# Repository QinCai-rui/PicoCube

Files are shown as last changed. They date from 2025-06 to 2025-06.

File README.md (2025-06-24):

# RasPiCube

## A Raspberry Pi-powered Rubik's Cube Timer

Rubik's Cube Timer

_NOTE: The image shows (simulated on Wokwi) demo powered by a Raspberry Pi Pico_

## Why I Made This Project

Honestly, I just wanted a cool timer for solving Rubik’s Cubes—something I could build myself, mess with, and show off to friends at school. The ones you can buy are fine, but making my own with a Raspberry Pi felt way more fun (and gave me an excuse to tinker with hardware and code). Now I’ve got a timer that does exactly what I want (although there are a few bugs to fix, and some features yet-to-be-implemented), and I learned a ton making it!! And it's portable, too! :)

## Overview

RasPiCube is a portable, Raspberry Pi Zero 2 W(H)-powered Rubik's Cube timer and scramble generator. This DIY project combines a high-resolution (320x240, pretty high) display, 7-segment timer, touch sensor input, and RGB status indicators to create a timing solution for cubers like myself.

### Features

- **Scramble Generation**: Automatically generates random, valid 3x3 Rubik's Cube scrambles
- **Dual Display System**: 
  - 2-inch IPS LCD Display (240×320) for scramble and statistics
  - 6-digit 7-segment display for precise timing readout (3d.p.)
- **Touch Sensor Input**: Capacitive touch controls for a competition-like solving experience 
- **Visual Status Indicators**: RGB LED provides clear visual feedback of the project's status
- **Statistics**: Calculates and displays session averages (ao5, ao12)
- **Battery Powered**: Portable with a 18650 lithium-ion battery

### Case (just a box for now. will modify it after getting the parts and done some measurements)



### Circuit diagram (in ASCII; it's bad, I know)

I couldn't find footprints/symbols for most of the parts I am using. Sooo.
 [diagram here](https://github.com/QinCai-rui/RasPiCube/blob/main/DIAGRAM/diagram.txt)

### What it will end up looking like

Note: this is a picture taken in Wokwi simulator, with a very early version of this project that (barely) runs on the Raspberry Pi Pico. 
Rubik's Cube Timer

## Hardware Components

For a complete list of components and estimated prices, please see [BOM.md](https://github.com/QinCai-rui/RasPiCube/blob/main/BOM/BOM.md).

## What’s What (What Each File/Folder Is For)

- **.gitignore** — Tells git which files/folders to ignore (so junk/config and cache files don’t get tracked).
- **BOM/** — Bill of Materials! All the parts I need and some prices. See this for shopping. (required by Highway)
- **CAD/** — 3D model files for the timer’s case. Print or edit them if you want to make/modify the enclosure.
  - `RasPiCube_Case.step` — The actual 3D model of the case.
- **DIAGRAM/** — Circuit diagrams and wiring info.
  - `diagram.txt` — Text version of the wiring/circuit diagram. (bc I couldn't find footprints/symbols for most of the parts I am using)
- **JOURNAL.md** — My build log, notes, and what worked/didn’t along the way.
- **LICENSE** — Legal stuff (open source license details).
- **README.md** — You’re reading it rn! All the info about the project.
- **pi02w-rubiks.py** — The main code that runs the timer and scramble generator on the RPi Zero 2 W.
- **proofOfConcept/** — Early test code and experiments before the main build. These can run on any OS with Python 3 installed. No special hardware needed.
  - `basic_scramble_3x3.py` — Simple script to generate 3x3 scrambles (terminal version).
  - `rubiks_terminal.py` — Terminal-based prototype timer/scrambler.

## Circuit Diagram

See [diagram.txt](DIAGRAM/diagram.txt).

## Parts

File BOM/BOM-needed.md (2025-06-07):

# PiCubeZero - Bill of Materials (parts needed)

---

## Core Components

| Component | Description | Quantity | Link | Est. Price (inc. shipping) | Purpose |
|---|---|---|---|---|---|
| 802.11ax USB adapter | WiFi 6, mt7921au, dual-band | 1 | [AliExpress](https://www.aliexpress.com/item/1005005935638503.html) | $1.72 | 5GHz WiFi 6 networking; our home network does not have working 2.4GHz..... |
| 2-inch IPS LCD Display | 240x320 ST7789, Waveshare compatible | 1 | [Amazon](https://www.amazon.com/LCD-2inch-Module-Compatible-Display/dp/B0DRS9YQCK) | $14.40 | Scramble/time/statistics display |
| 6-Digit 7-Segment Display| TM1637-compatible LED display module | 1 | [AliExpress](https://www.aliexpress.com/item/1005001582129952.html) | $2.64 | Real-time/final time display |
| TTP223 Touch Sensor | Capacitive touch sensor | 2 | [AliExpress](https://www.aliexpress.com/item/1005006153014582.html) | $1.70 | Start/stop timer input |
| RGB LED (Common Cathode) | 5mm tri-color diffused | 1 | [AliExpress](https://www.aliexpress.com/item/1005004963591071.html) | $3.18 (100x)| Status indicator (colour coding) |

---

## Additional Components & Accessories

| Component | Description | Quantity | Link | Est. Price | Purpose |
|---|---|---|---|---|---|
| Resistors | 220Ω for RGB LED (x3) | 3 | [AliExpress](https://www.aliexpress.com/item/1005008494728485.html) | $5.58 (600x) | Current limiting for RGB LED |
| Wires | Solid core, white, 24AWG | 10 metres | [AliExpress](https://www.aliexpress.com/item/1005006106330815.html) | $2.10 | Connecting components |
| Large Breadboard | 630 holes | 1 | [AliExpress](https://www.aliexpress.com/item/1005007085965483.html) | $1.54 | Housing the electronics |
| Protoboard | 400 holes | 5 | [AliExpress](https://www.aliexpress.com/item/1005007204514719.html) | $9.31 | To solder the electronics on |
| USB Cable | Data, USB 2.0, 1m | 1 | [AliExpress](https://www.aliexpress.com/item/1005007504624576.html) | $0.99 | For data transfer and Pi first-boot configuration |
| Foam Tape | Double Sided Adhesive Foam Tape - 1.5cm, 5m | 1 | [AliExpress](https://www.aliexpress.com/item/1005006891100106.html?) | $0.99 | Temporary mounting and fixing electronics |
| Li-ion Battery | 18650 3.7V 3500mAh | 1 | [AliExpress](https://www.aliexpress.com/item/1005008078553867.html) | $4.98 | Powering the electronics |
| Battery Charger & Booster | Charging Circuit Board Step Up Boost Power Supply Module; 2xUSB-A output | 1 | [AliExpress](https://www.aliexpress.com/item/1005007457573822.html) | $0.59 | Charging and converting battery to 5V |
| 18650 Holder | Holder with cable | 1 | [AliExpress](https://www.aliexpress.com/item/1005006089547043.html) | $0.99 | Holder for 18650 battery
---

## Totals

### AliExpress



US$46.81

### Amazon


US$16.56

### Grant Total
US$63.37 GRAND TOTAL

---

## Notes

- Use only 1 RGB LED from the pack of 100.
- Use only 3 resistors from the pack of 600.
- The microSD card (64GB) is more than sufficient for OS and solve log storage.
- All links and prices were last verified as of 2025-06-02.

---

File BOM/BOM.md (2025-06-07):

# PiCubeZero - Bill of Materials

---

## Core Components

| Component | Description | Quantity | Link | Est. Price (inc. shipping) | Purpose |
|---|---|---|---|---|---|
| Raspberry Pi Zero 2 WH | 1GHz quad-core ARM CPU with WiFi, BT, and header pins| 1 | [AliExpress](https://www.aliexpress.com/item/1005007982832720.html) | $24.93 | Main controller/computer for the timer |
| 802.11ax USB adapter | WiFi 6, mt7921au, dual-band | 1 | [AliExpress](https://www.aliexpress.com/item/1005005935638503.html) | $1.72 | 5GHz WiFi 6 networking; our home network does not have working 2.4GHz..... |
| 2-inch IPS LCD Display | 240x320 ST7789, Waveshare compatible | 1 | [Amazon](https://www.amazon.com/LCD-2inch-Module-Compatible-Display/dp/B0DRS9YQCK) | $14.40 | Scramble/time/statistics display |
| 6-Digit 7-Segment Display| TM1637-compatible LED display module | 1 | [AliExpress](https://www.aliexpress.com/item/1005001582129952.html) | $2.64 | Real-time/final time display |
| TTP223 Touch Sensor | Capacitive touch sensor | 2 | [AliExpress](https://www.aliexpress.com/item/1005006153014582.html) | $1.70 | Start/stop timer input |
| SanDisk Extreme microSD | 64GB, Class A2, 190MB/s | 1 | [Amazon](https://www.amazon.com/SanDisk-Extreme-microSDXC-Memory-Adapter/dp/B09X7C7LL1) | $11.27 | OS and storage |
| RGB LED (Common Cathode) | 5mm tri-color diffused | 1 | [AliExpress](https://www.aliexpress.com/item/1005004963591071.html) | $3.18 (100x)| Status indicator (colour coding) |

---

## Additional Components & Accessories

| Component | Description | Quantity | Link | Est. Price | Purpose |
|---|---|---|---|---|---|
| Resistors | 220Ω for RGB LED (x3) | 3 | [AliExpress](https://www.aliexpress.com/item/1005008494728485.html) | $5.58 (600x) | Current limiting for RGB LED |
| Wires | Solid core, white, 24AWG | 10 metres | [AliExpress](https://www.aliexpress.com/item/1005006106330815.html) | $2.10 | Connecting components |
| Large Breadboard | 630 holes | 1 | [AliExpress](https://www.aliexpress.com/item/1005007085965483.html) | $1.54 | Housing the electronics |
| Protoboard | 400 holes | 5 | [AliExpress](https://www.aliexpress.com/item/1005007204514719.html) | $9.31 | To solder the electronics on |
| USB Cable | Data, USB 2.0, 1m | 1 | [AliExpress](https://www.aliexpress.com/item/1005007504624576.html) | $0.99 | For data transfer and Pi first-boot configuration |
| Foam Tape | Double Sided Adhesive Foam Tape - 1.5cm, 5m | 1 | [AliExpress](https://www.aliexpress.com/item/1005006891100106.html?) | $0.99 | Temporary mounting and fixing electronics |
| Li-ion Battery | 18650 3.7V 3500mAh | 1 | [AliExpress](https://www.aliexpress.com/item/1005008078553867.html) | $4.98 | Powering the electronics |
| Battery Charger & Booster | Charging Circuit Board Step Up Boost Power Supply Module; 2xUSB-A output | 1 | [AliExpress](https://www.aliexpress.com/item/1005007457573822.html) | $0.59 | Charging and converting battery to 5V |
| 18650 Holder | Holder with cable | 1 | [AliExpress](https://www.aliexpress.com/item/1005006089547043.html) | $0.99 | Holder for 18650 battery
---

## Wiring Reference

| Component | Raspberry Pi Zero 2 W Connection |
|---|---|
| 2-inch LCD Display | VCC→3.3V, GND→GND, DIN/MOSI→GPIO10, CLK→GPIO11, CS→GPIO8, DC→GPIO25, RST→GPIO27, BL→GPIO24 |
| 6-Digit 7-Segment | CLK→GPIO5, DIO→GPIO6, VCC→5V, GND→GND |
| RGB LED (Common Cathode) | Common→GND, R→220Ω→GPIO17, G→220Ω→GPIO22, B→220Ω→GPIO4 |
| TTP223 Touch Sensor | Signal→GPIO23, VCC→3.3V, GND→GND |

---

## Notes

- Use only 1 RGB LED from the pack of 100.
- Use only 3 resistors from the pack of 600.
- The microSD card (64GB) is more than sufficient for OS and solve log storage.
- All links and prices were last verified as of 2025-06-02.

---

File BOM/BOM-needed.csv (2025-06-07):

Component | Description | Quantity | Link | Est. Price | Purpose
802.11ax USB adapter | WiFi 6, mt7921au, dual-band | 1 | https://www.aliexpress.com/item/1005005935638503.html | $1.72 | 5GHz WiFi 6 networking
2-inch IPS LCD Display | 240x320 ST7789, Waveshare compatible | 1 | https://www.amazon.com/LCD-2inch-Module-Compatible-Display/dp/B0DRS9YQCK | $14.40 | Scramble/time/statistics display
6-Digit 7-Segment Display | TM1637-compatible LED display module | 1 | https://www.aliexpress.com/item/1005001582129952.html | $2.64 | Real-time/final time display
TTP223 Touch Sensor | Capacitive touch sensor | 2 | https://www.aliexpress.com/item/1005006153014582.html | $1.70 | Start/stop timer input
RGB LED (Common Cathode) | 5mm tri-color diffused | 1 | https://www.aliexpress.com/item/1005004963591071.html | $3.18 (100x) | Status indicator (colour coding)
Resistors | 220Ω for RGB LED (x3) | 3 | https://www.aliexpress.com/item/1005008494728485.html | $5.58 (600x) | Current limiting for RGB LED
Wires | Solid core, white, 24AWG | 10 metres | https://www.aliexpress.com/item/1005006106330815.html | $2.10 | Connecting components
Large Breadboard | 630 holes | 1 | https://www.aliexpress.com/item/1005007085965483.html | $1.54 | Housing the electronics
Protoboard | 400 holes | 5 | https://www.aliexpress.com/item/1005007204514719.html | $9.31 | To solder the electronics on
USB Cable | Data, USB 2.0, 1m | 1 | https://www.aliexpress.com/item/1005007504624576.html | $0.99 | For data transfer and Pi first-boot configuration
Foam Tape | Double Sided Adhesive Foam Tape - 1.5cm, 5m | 1 | https://www.aliexpress.com/item/1005006891100106.html | $0.99 | Temporary mounting and fixing electronics
Li-ion Battery | 18650 3.7V 3500mAh | 1 | https://www.aliexpress.com/item/1005008078553867.html | $4.98 | Powering the electronics
Battery Charger & Booster | Charging Circuit Board Step Up Boost Power Supply Module; 2xUSB-A output | 1 | https://www.aliexpress.com/item/1005007457573822.html | $0.59 | Charging and boosting battery output for the project
18650 Holder | Holder with cable | 1 | https://www.aliexpress.com/item/1005006089547043.html | $0.99 | Holder for 18650 battery

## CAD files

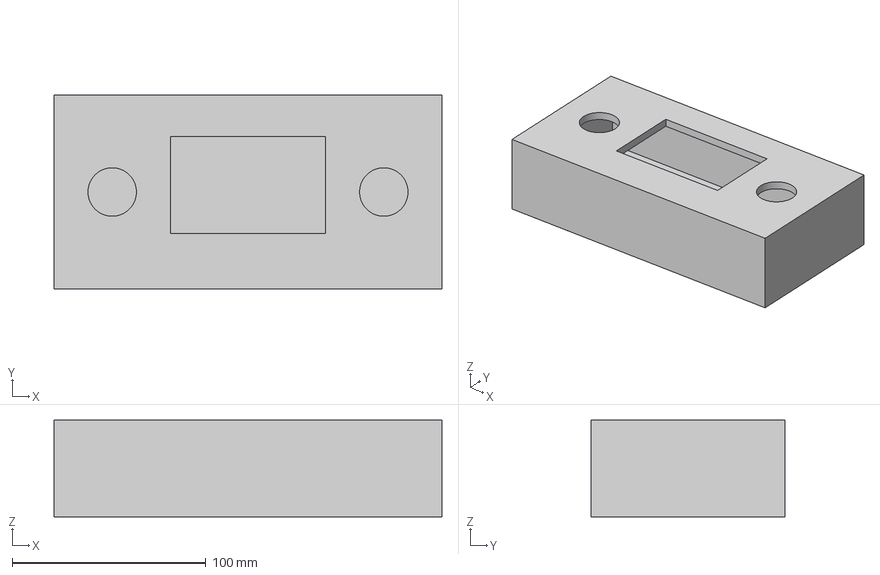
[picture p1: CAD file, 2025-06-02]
CAD/RasPiCube_Case.step
200.0 x 100.0 x 50.0 mm

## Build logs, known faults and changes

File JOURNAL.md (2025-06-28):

---
title: "RasPiCube"
author: "@QinCai-rui"
description: "A Raspberry Pi powered Rubik's cube timer and scramble generator"
created_at: "2025-05-16"
---

**TOTAL TIME:** 35 hours

## 16/5/25

### Update 1/1

In around **30 minutes** I managed to create a Prove-of-Concept (PoC) version of a 3x3 Rubik's Cube scramble generator. The code is pretty simple and straightforward, so I'm not gonna waste time describing how it works.

basic scramble generator in action

---------------------

### Update 2/2

Another **1 hour and a bit**, a _proper_ timer and scramble generator was born. I integrated the old scrable generator into the new program, by importing it as a module.

I kind of struggled at first to make the timing work, because the code on line 31 somehow "redefined" the `time` module, which gave me wheird errors:

```python
Traceback (most recent call last):
  File "/home/qincai/PicoCube/test.py", line 76, in <module>
    main()
    ~~~~^^
  File "/home/qincai/PicoCube/test.py", line 51, in main
    start_time = time.time()
                 ^^^^
UnboundLocalError: cannot access local variable 'time' where it is not associated with a value
```

so i changed `time` to `solve_time` :))

Another challenge was to display the real-time timer, which every rubiks cube timer should have. In the older real-time version of this program, the user had to press `CTRL+C` to trigger the timer stop, which is not ideal. Fortunately I worked _that_ out as well, using `threading`

---------------------

## 19/5/25

### Update 1/3

After about **1.5 hours** of hard grind, behold -- the `PiCubeZero`. Okay, im not even sure if it works or not, since I don't have the necessary hardware to build the project physically. That also means there is no pictures to share :((.

The process was pretty straightforward, since there is sooo much documentation on the Internet about the modules I was/am after. I fed the completed program into `GPT-4.1` to check for any mistakes and suggestions, and good -- no big mistakes, but a few changes were made, such as the font selection thing I do _not_ know how it works, or if it's supposed to work... 

---------------------

### Update 2/4

Another **50 -ish minutes** later and I (sort of, and the stupid `GPT-4.1` helped me **a lot**) made a version of PiCube, called "PiCubePico", since it is based on the Raspberry Pi Pico MCU. Check it out here on Wokwi Simulator: <https://wokwi.com/projects/431347174552980481>

Screenshot: 

_(pls ignore the inconsistency between the OLED screen and the 7-seg display. The simulator is **extremely** laggy, with one second simulated being 15+ secs in real life)_

---------------------

### Update 3/5

Spent like **1.5 hours** creating the BOM, and it is not even complete (yet). 
Here is the [BOM for RasPiCube - PiCubeZero](https://github.com/QinCai-rui/RasPiCube/blob/main/BOM/BOM.md)

---------------------

## 20/5/25

### Update 1/6

Just updated the RasPiCube - PiCubeZero program to use a Waveshare 2-inch IPS LCD Display (ST7789, 240x320), instead of a tiny SSD1306 128x64 OLED display. This time GPT-4.1 helped me a lot when updating the program since I made quite a lot of mistakes. 

Time spent this session: ~**1.5 hours**

---------------------

### Update 2/7

For this session, I worked a lot on the [PiCubeZero's BOM](https://github.com/QinCai-rui/RasPiCube/blob/main/BOM/BOM.md). I tried comparing the items I need on Aliexpress and Amazon. I almost got scammed by (likely) a scam on Aliexpress. [Link here](https://www.aliexpress.com/item/1005008269997334.html)

The "Sandian" branded uSD cards look sooo similar to the real "SanDisk" ones.

Screenshot 2025-05-20 at 6 42 54 PM
Screenshot 2025-05-20 at 6 43 13 PM

A quick Internet search revealed that...... "SanDian" is a scam. WHOO HOO. /j

Here are the posts:
[post1](https://forums.grc.com/threads/fake-1tb-sandian-micro-sdcard-test.1333/) 
[post2](https://bulkmemorycards.com/identifying-counterfeit-microsd-cards/)

Maybe just don't buy uSD cards from AliExpress... Buy them on Amazon instead ig.

Time spent this session: ~**1 hour**

---------------------

### Update 3/8

Since I couldn't find one single NeoPixel (as in 1 LED), I decided to switch to a common-cathode RGB LED. Simple! Also saved a bit of cash....

Time spent this session: **25 minutes**

---------------------

## 21/5/25

### Update 1/9

Updated the BOM to include all needed parts. This project is gonna cost a lot with a Pi 0 2WH, a battery, and a screen... (about $100 USD atm).

Amazon Total
AliExpress Total

Time spent this session: **30 minutes**

---------------------

## 2/6/25

### Update 1/10

Update the BOM once again to only include the parts that i need. This brings the cost down to ~$60. See [BOM-needed.md](BOM/BOM-needed.md).


Time spent this session: **20 minutes**

---------------------

### Update 2/11

Cleanned up the repo!! There is nothing more i could say..

Time spent this session: **25 minutes**

---------------------

## 7/6/25

### Update 1/12

Spent **1.5 hours** looking for a better USB WiFi adapter. Ended up finding this one on AliExpress:  
[FENVI 1800Mbps WiFi 6 USB Adapter Dual Band 2.4G/5Ghz Wireless WiFi Receiver USB 3.0 Dongle Network Card](https://www.aliexpress.com/item/1005005935638503.html)

Turns out, this adapter is actually listed in [morrownr's Linux USB WiFi compatibility list](https://github.com/morrownr/USB-WiFi/blob/main/home/USB_WiFi_Adapters_that_are_supported_with_Linux_in-kernel_drivers.md), so it should work just fine out of the box. It’s the Fenvi FU-AX1800 (uses the mt7921au chipset), which is pretty much plug-and-play on any recent Linux, as long as you’re not running some ancient kernel from the Stone Age (ahem, looking at Raspberry Pi OS, which just migrated to 6.12).

Some random thoughts:

- mt7921au = good chipset, Linux likes it, no weird drivers, just works (or so i hope).
- Loads of positive reviews from other Linux nerds online, especially on AliExpress and in that repo.
- It’s super cheap ($1.72 with Welcome Deal). Not gonna break HC's bank.
- Just double check you don’t get tricked into buying the Realtek version — only mt7921au is the good one. -- from the repo

Added this to my BOM cos I need WiFi. Anyway, very happy with this find!

(surprisingly, this much better wifi adapter only brought up my BOM by about $5. It's prob Aliexpress' Welcome Deal thingy)

_see (BOM)[https://github.com/QinCai-rui/RasPiCube/blob/432650de670bce71bf1978ce57de217eb192d6ab/BOM/BOM-needed.md] for my BOM at the time of writing_

Time spent: **1 hour** (browsing, comparing, reading reviews, dodging dodgy sellers on Ali)

---------------------

## 19/6/25 - 23/6/25

### Update 1/13

YAY I got my packages for my project, and I immediately started putting it together. To my surprise, AliExpress' stuff are not _that_ bad. Since my Raspberry Pi Zero 2 W from [#raspap](https://hackclub.slack.com/archives/C07UZSKJQRX), which I planned to use initially, still hasn't even shipped (!!!!!!) (SMH, insert sad face, insert :heavy-sob: emoji)

Since I do not wait **another** 6 months for my Pi to ship from the USA to New Zealand, I put my idle Raspberry Pi Pico (WH) into work. Surprisingly (again), there is a library for the LCD screen I am using. So I installed MicroPython on the Pico, copied the library across in the `lib/` directory, and discovered -- that I need fonts "libraries" to display text. Thankfully (why are there so many adverbs..), the GitHub repo of that library includes some so-called "ROM Fonts", so again, I downloaded the 32x16 and 16x8 fonts onto the Pico, in the `lib/` directory.

I then started to convert the previously made-for-the-better-and-faster-pi02w Python program into the MicroPython version the Pico requires. I had to keep in mind the different pin allocations and stuff, which was pretty annoying, but manageable. It took like 2 and a bit hours, but there it is - a fully functional (Micro)Python code that can run the the Pico, or so I hoped. I named the file `main.py` so that it automatically starts on boot.

Things are not as easy as i thought, however. The screen's rotation was wrong; I wanted it to be horizontal, but instead it was verticle. Also, some text are clipped off the screen. To make matter even worse, the touch sensor did not do _anything_. I left some of hard work to GitHub Copilot to fix the rotation and text clipping, and I tried to change to a different touch sensor, since it came in a pack of 5.

To my surprise (this time negatively), the touch sensor I was initially using is faulty; a quick test with another sensor quickly comfirmed that. Ahhh, AliExpress, maybe you are not that reliable. 

upon repeatition of the test on other sensors, another one (with clearly visible damage) turned out to be faulty... OOF. Two in a row, that leaves 3 working sensors left, and 2 in use, leaving **only** 1 backup sensor. URGHHH.. I WANT SOME BACKUP SENSORS SO I DONT HAVE TO FEAR THAT A TOUCH WILL BREAK ONE (given the reliability, or lack thereof AliExpress items) But it is what it is, and I decided it was enough work for one day.

The next day, although I forgot the date, I started fixing the remaining of the not-working parts of the program. Copilot did most of the work, fixing my logic errors and stuff. This makes me think, if in the future, LLMs like Claude, get even "smarter" and more "reliable", would there be any demand for programmers at all? Even program testers would not be needed anymore if the LLMs could self-test their program. And just a month ago (iirc), [GitHub introduced Agent Mode for their GitHub Copilot](https://github.blog/ai-and-ml/github-copilot/agent-mode-101-all-about-github-copilots-powerful-mode/). According to their blog, the Agent Mode Copilot is capable of:

    Analyze your codebase to grasp the full context.
    Plan and execute multi-step solutions.
    Run commands or tests.
    Reach out to external tools for specialized tasks.
    Suggest architectural improvements.
    Run and refine its own work through an agentic loop, including planning, applying changes, testing, and iterating.

This makes me think: isn't that myself, and most other human programmers are currently doing? If LLMs _really_ do became more powerful, again, would there be **_any_** point at all having programmers around in that stage? What would be the point of learning programming, for future programmers, if LLMs can do it better than us? I guess we will have to wait and see.

Anyways, GitHub Copilot did help me a lot, and I managed to get the program working. I then tested it on the Pico, and it worked! The touch sensor was working, the screen was displaying the text correctly, and the timer was working as expected. I was very happy with the result, and I decided to call it a day.

But nope. I had more ideas to implement, but I thought I should leave them for another day. I had a lot of fun working on and playing with this project.

Time spent this session: **7 hours** (including the time unboxing the stuff, testing the touch sensors, and fixing the program)

---------------------

## 24/6/25

### Update 1/14

For this session, I fixed most of the bugs introduced by the previous session. For example, there is the issue that the timer does not start when the user releases the touch sensor, but only when the user presses it. This is not ideal, since the user might accidentally release the touch sensor before they are ready to start the timer. I fixed this by adding a delay of 0.4 seconds before starting the timer, so that the user has time to get ready.

Time spent this session: **2 hours** (including the time to test the program on the Pico and fix the bugs)

--------------------

## 25/6/25 - 28/6/25

### Update 1/15

These sessions were spent on soldering the header pins onto the Raspberry Pi Zero 2W, downloading the latest Raspberry Pi OS, and setting up the Pi Zero 2W. I also had to install the necessary libraries and dependencies for the program to run. This took a lot of time, since I had to figure out how to do it on a headless Raspberry Pi, without a monitor or keyboard. I had to use SSH to connect to the Pi and run the commands. Good thing I enabled SSH on the Pi before I started, otherwise I would have been stuck; I also enabled the `rc-local` service to run commands on boot, just in case, you never know. I also configured Ethernet Gadget mode, so that I can connect the Pi to my computer via USB and access the internet. This is very useful, since I don't have a monitor or keyboard for the Pi. Unfortunately I could not figure out how to make a bridge network between the Pi and my Linux computer, so internet access is not available on the Pi. I will have to figure that out later.

Time spent this session: **4 hours** (including the time to solder the header pins, download the Raspberry Pi OS, and set up the Pi Zero 2W)

---------------------

### Update 2/16

Since I ordered a USB WiFi adapter, I connected it to the Pi, and, surprisingly, it worked out of the box. I was able to connect to my WiFi network and access the internet. This is very useful, since I can now update the Pi and install the necessary libraries and dependencies for the program to run. I also installed the `git` command, so that I can clone the repository and run the program on the Pi. Some more libraries also had to be installed, but the pi02w is sooooo slow that it took like 30 minutes to install the libraries using `pip`. `btop` later showed that the Pi's CPU only goes up to 700MHz for some reason, even though I set the `arm_freq` to 1150MHz in the `config.txt` file. So I had to set the `arm_freq_min` option to `900` in the `config.txt` file, which allows the Pi to run at full speed all the time. This is not ideal, since it will drain power faster, but I don't have a choice.

Time spent this session: **2 hours** (including the time to connect the USB WiFi adapter, update the Pi, and install the necessary libraries and dependencies)

---------------------

### Update 3/17

I spent this session working on the program itself. I had to modify the program to work with the Raspberry Pi Zero 2W, since it has a different pin allocation and different libraries. I also had to modify the program to work with the Waveshare 2-inch IPS LCD Display, since it has a different library and different functions. I had to figure out how to use the `st7789` library to display text and images on the screen. 

For some reason, the `st7789` library did not do anything to the screen, so I had to switch to the `luma.lcd` library, which is a more general library for LCD displays. I had to modify the program to use the `luma.lcd` library instead of the `st7789` library, and it worked! I was able to display text and images on the screen, and the touch sensors weer working as expected. 

Time spent this session: **4 hours** (including the time to modify the program to work with the Raspberry Pi Zero 2W and the Waveshare 2-inch IPS LCD Display)

---------------------

### Update 4/18

This session was all about testing. Soo I did a bunch of solves :))

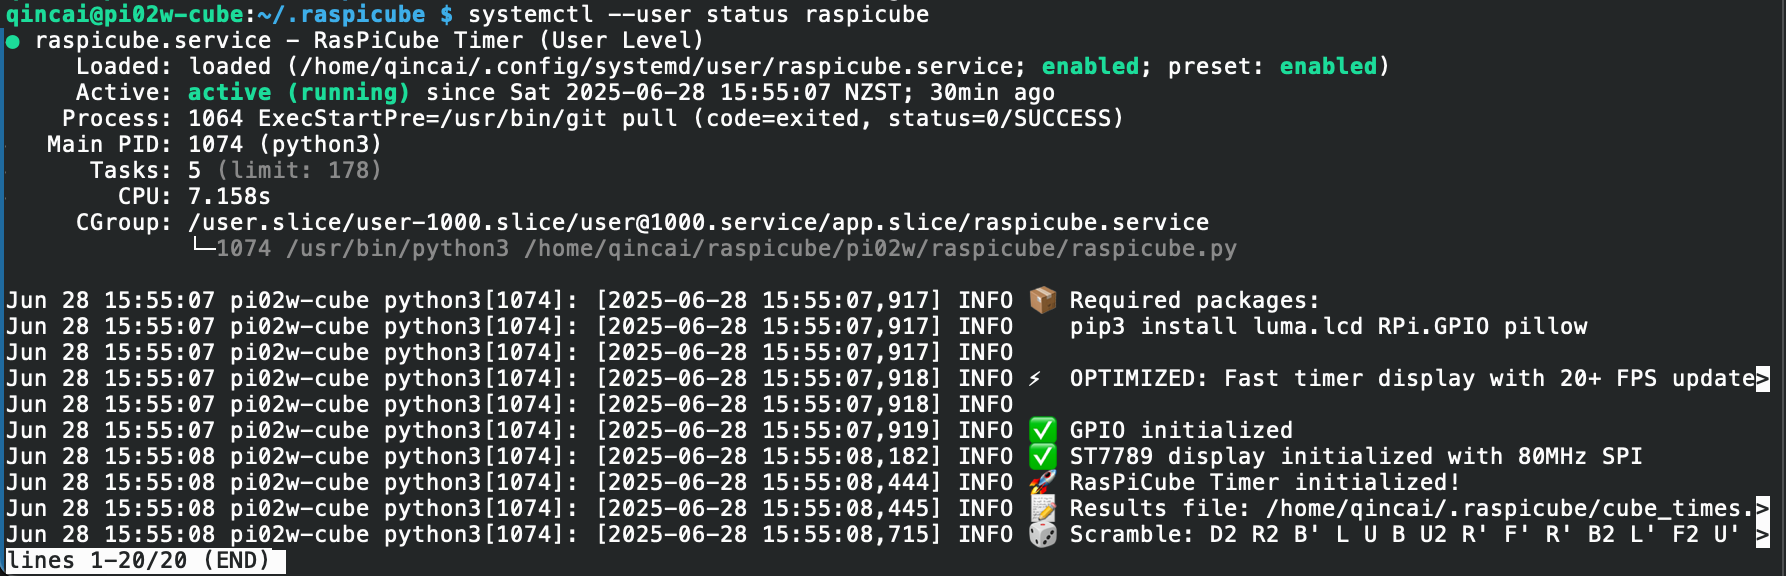
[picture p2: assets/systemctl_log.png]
systemctl log


Unfortunately, if I unplug the USB WiFi adapter, the Pi will not be able to connect to the internet, since it does not have a built-in WiFi adapter that supports 5Ghz band. Therefore the `ExecStartPre` command (`git pull`) in the `systemd` service file will not work, and the service will not continue to start.

git pull error

I had to modify the `systemd` service file make the `ExecStartPre` command always exit 0, no matter what.

Time spent this session: **5 hours**

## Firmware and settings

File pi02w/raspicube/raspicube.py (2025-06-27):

#!/usr/bin/env python3
"""
######## THIS IS ENTIRELY REWRITTEN FOR THE PI ZERO 2W BY GITHUB COPILOT ########

Original Pico version by myself, @QinCai-rui, https://qincai.xyz

RasPiCube - Complete Pi Zero 2W port of Pico Rubik's Cube Timer
Replicates ALL functionality from the original Pico version including:
- Full display UI with proper fonts and colors
- Backlight management with touch-to-wake
- Timer control with hold/release logic
- Results display with averages (ao5, ao12)
- Clear history with confirmation dialog
- Version display
- Proper button handling and debouncing
- OPTIMIZED: Fast timer display with 20+ FPS updates
"""

import time
import random
import json
import os
import logging
from pathlib import Path
# from datetime import datetime
# import sys

# Set up logging so systemd and journalctl will capture the output
logging.basicConfig(
    level=logging.INFO,
    format='[%(asctime)s] %(levelname)s %(message)s'
)
logger = logging.getLogger("raspicube")

# GPIO libraries for Pi
import RPi.GPIO as GPIO

# Display libraries - using luma.lcd instead of st7789
from luma.core.interface.serial import spi
from luma.core.render import canvas
from luma.lcd.device import st7789
from PIL import Image, ImageDraw, ImageFont

VERSION = "v1.7.1-rpi"

# GPIO Pin definitions (BCM numbering)
TIMER_PIN = 26
NEXT_PIN = 19

# Display dimensions - using actual ST7789 resolution
DISPLAY_WIDTH = 320
DISPLAY_HEIGHT = 240

# Colors (RGB tuples)
class Colors:
    BLACK = (0, 0, 0)
    WHITE = (255, 255, 255)
    RED = (255, 0, 0)
    GREEN = (0, 255, 0)
    BLUE = (0, 0, 255)
    CYAN = (0, 255, 255)
    MAGENTA = (255, 0, 255)
    YELLOW = (255, 255, 0)

# Rubik's cube settings (same as Pico)
faces = ['U', 'D', 'L', 'R', 'F', 'B']
modifiers = ['', "'", '2']
opposite = {'U':'D', 'D':'U', 'L':'R', 'R':'L', 'F':'B', 'B':'F'}

RESULTS_FILE = os.path.expanduser("~/.raspicube/cube_times.json")

# Backlight management (same as Pico)
BACKLIGHT_TIMEOUT_MS = 20000
BACKLIGHT_SOLVE_EXTRA_MS = 10000
SCRAMBLE_BACKLIGHT_TIMEOUT_MS = 30000  # 30 seconds on scramble screen

class FontManager:
    """Manage fonts to match Pico's font sizes"""
    def __init__(self):
        self.font_paths = [
            "/usr/share/fonts/truetype/dejavu/DejaVuSansMono-Bold.ttf",
            "/usr/share/fonts/truetype/liberation/LiberationMono-Bold.ttf",
            "/usr/share/fonts/truetype/dejavu/DejaVuSans-Bold.ttf",
            "/usr/share/fonts/truetype/liberation/LiberationSans-Bold.ttf"
        ]
        
        # Font sizes matching Pico's vga1_16x32 and vga1_8x16
        self.big_font = self._load_font(28)    # Larger for 320x240 display
        self.small_font = self._load_font(14)  # Adjusted for readability
        
        # Calculate font metrics
        self.big_width = 18
        self.big_height = 32
        self.small_width = 9
        self.small_height = 16
    
    def _load_font(self, size):
        """Load the best available font"""
        for path in self.font_paths:
            try:
                return ImageFont.truetype(path, size)
            except:
                continue
        return ImageFont.load_default()

class PiCubeTimer:
    def __init__(self):
        # Create the directory if it doesn't exist
        results_dir = os.path.dirname(RESULTS_FILE)
        Path(results_dir).mkdir(parents=True, exist_ok=True)
        
        # Rest of initialization remains the same
        self.setup_gpio()
        self.setup_display()
        self.font_manager = FontManager()
        self.setup_timer_buffer()
        
        # State management with better error handling
        self.solve_times = self.load_times()
        self.last_touch_time = self.ticks_ms()
        self.backlight_on = True
        
        logger.info("🚀 RasPiCube Timer initialized!")
        logger.info(f"📝 Results file: {RESULTS_FILE}")
    
    def setup_gpio(self):
        """Initialize GPIO pins"""
        GPIO.setwarnings(False)
        GPIO.setmode(GPIO.BCM)
        GPIO.setup(TIMER_PIN, GPIO.IN, pull_up_down=GPIO.PUD_DOWN)
        GPIO.setup(NEXT_PIN, GPIO.IN, pull_up_down=GPIO.PUD_DOWN)
        logger.info("✅ GPIO initialized")
    
    def setup_display(self):
        """Initialize the ST7789 display using luma.lcd"""
        try:
            # OPTIMIZED: Higher SPI speed for faster updates
            self.serial = spi(port=0, device=0, gpio_DC=24, gpio_RST=25, spi_speed_hz=80000000)
            
            # Initialize ST7789 device
            self.device = st7789(self.serial, width=DISPLAY_WIDTH, height=DISPLAY_HEIGHT, rotate=0)
            
            logger.info("✅ ST7789 display initialized with 80MHz SPI")
            
            # Initialize with black screen
            self.fill_screen(Colors.BLACK)
            
        except Exception as e:
            logger.error(f"❌ Failed to initialize display: {e}")
            self.device = None
    
    def setup_timer_buffer(self):
        """Create persistent buffer for fast timer updates"""
        self.timer_buffer = Image.new('RGB', (DISPLAY_WIDTH, DISPLAY_HEIGHT), Colors.BLACK)
        self.timer_draw = ImageDraw.Draw(self.timer_buffer)
        self.last_timer_str = ""
    
    def ticks_ms(self):
        """Get current time in milliseconds (like Pico's time.ticks_ms())"""
        return int(time.time() * 1000)
    
    def ticks_diff(self, new_ticks, old_ticks):
        """Calculate time difference (like Pico's time.ticks_diff())"""
        return new_ticks - old_ticks
    
    def sleep_ms(self, ms):
        """Sleep for milliseconds (like Pico's time.sleep_ms())"""
        time.sleep(ms / 1000.0)
    
    # Display functions using luma.lcd
    def fill_screen(self, color):
        """Fill entire screen with color"""
        if self.device:
            try:
                with canvas(self.device) as draw:
                    draw.rectangle(self.device.bounding_box, fill=color)
            except Exception as e:
                logger.error(f"Display error in fill_screen: {e}")
    
    def draw_text(self, draw, text, x, y, font, color):
        """Draw text with the given parameters"""
        draw.text((x, y), text, font=font, fill=color)
    
    def create_display_image(self, draw_func):
        """Create and display an image using the provided drawing function"""
        if self.device:
            try:
                with canvas(self.device) as draw:
                    draw_func(draw)
            except Exception as e:
                logger.error(f"Display error: {e}")
    
    # OPTIMIZED TIMER DISPLAY - Fast updates with frame buffer
    def display_timer_fast(self, time_val, running=True):
        """OPTIMIZED timer display - only updates changed areas"""
        timer_str = "{:6.1f}".format(time_val) if running else "{:6.2f}".format(time_val)
        
        # Only redraw if timer value actually changed
        if timer_str != self.last_timer_str:
            # Get text size
            timer_bbox = self.timer_draw.textbbox((0, 0), timer_str, font=self.font_manager.big_font)
            timer_width = timer_bbox[2] - timer_bbox[0]
            timer_height = timer_bbox[3] - timer_bbox[1]
            
            x_timer = max(0, (DISPLAY_WIDTH - timer_width) // 2)
            y_timer = (DISPLAY_HEIGHT - timer_height) // 2
            
            # Clear only the timer area (not whole screen)
            self.timer_draw.rectangle([
                x_timer - 10, y_timer - 10, 
                x_timer + timer_width + 10, y_timer + timer_height + 10
            ], fill=Colors.BLACK)
            
            # Draw new timer
            color = Colors.GREEN if running else Colors.CYAN
            self.timer_draw.text((x_timer, y_timer), timer_str, font=self.font_manager.big_font, fill=color)
            
            # Push to display directly (bypass canvas overhead)
            if self.device:
                self.device.display(self.timer_buffer)
            
            self.last_timer_str = timer_str

    def clear_timer_buffer(self):
        """Clear the timer buffer"""
        self.timer_draw.rectangle([(0, 0), (DISPLAY_WIDTH, DISPLAY_HEIGHT)], fill=Colors.BLACK)
        self.last_timer_str = ""
    
    # Backlight management
    def set_backlight(self, state):
        """Set the backlight state"""
        self.backlight_on = state
        # Note: luma.lcd handles backlight automatically
    
    def update_touch_time(self):
        """Update the last touch time and wake backlight if needed"""
        self.last_touch_time = self.ticks_ms()
        if not self.backlight_on:
            self.set_backlight(True)
    
    def check_backlight_timeout(self, timeout_ms=None):
        """Check if backlight should be turned off due to timeout"""
        effective_timeout = timeout_ms if timeout_ms is not None else BACKLIGHT_TIMEOUT_MS
        if self.backlight_on and self.ticks_diff(self.ticks_ms(), self.last_touch_time) > effective_timeout:
            self.set_backlight(False)
            return True
        return False
    
    def any_touch(self):
        """Check if any button is pressed"""
        return GPIO.input(TIMER_PIN) or GPIO.input(NEXT_PIN)
    
    # Core timer functions
    def load_times(self):
        """Load solve times from file with better error handling"""
        try:
            if os.path.exists(RESULTS_FILE):
                with open(RESULTS_FILE, "r") as f:
                    return json.load(f)
            else:
                logger.warning(f"⚠️ No existing results file found at {RESULTS_FILE}")
                return []
        except json.JSONDecodeError as e:
            logger.warning(f"⚠️ Error reading results file: Invalid JSON format - {e}")
            # Backup corrupted file
            if os.path.exists(RESULTS_FILE):
                backup = f"{RESULTS_FILE}.bak"
                try:
                    os.rename(RESULTS_FILE, backup)
                    logger.info(f"📦 Corrupted file backed up to {backup}")
                except OSError as e:
                    logger.error(f"❌ Failed to backup corrupted file: {e}")
            return []
        except OSError as e:
            logger.warning(f"⚠️ Error accessing results file: {e}")
            return []
        except Exception as e:
            logger.warning(f"⚠️ Unexpected error loading results: {e}")
            return []

    def save_times(self, times):
        """Save solve times to file with better error handling"""
        try:
            # Create temp file
            temp_file = f"{RESULTS_FILE}.tmp"
            with open(temp_file, "w") as f:
                json.dump(times, f, indent=2)
            
            # Atomic replace
            if os.name == 'nt':  # Windows
                if os.path.exists(RESULTS_FILE):
                    os.remove(RESULTS_FILE)
            os.rename(temp_file, RESULTS_FILE)
            
        except OSError as e:
            logger.error(f"❌ Error saving times: {e}")
            if os.path.exists(temp_file):
                try:
                    os.remove(temp_file)
                except:
                    pass
        except Exception as e:
            logger.error(f"❌ Unexpected error saving times: {e}")
            if os.path.exists(temp_file):
                try:
                    os.remove(temp_file)
                except:
                    pass
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

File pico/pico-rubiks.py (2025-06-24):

import machine
import time
import random

# screen library
import st7789py as st7789

# fonts
import vga1_16x32 as font_big
import vga1_8x16 as font_small

# json processor for the log file
import ujson

VERSION = "v1.5.1-1"

# ST7789 driver dimensions (portrait mode)
TFT_WIDTH = 240  
TFT_HEIGHT = 320

# Physical dimensions in current orientation (landscape mode with rotation=1)
REAL_WIDTH = 320
REAL_HEIGHT = 240

spi = machine.SPI(1, baudrate=40000000, polarity=1, phase=0)    # Higher baudrate doesn't do anything somehow
tft = st7789.ST7789(
    spi,
    TFT_WIDTH,
    TFT_HEIGHT,
    reset=machine.Pin(12, machine.Pin.OUT),
    dc=machine.Pin(8, machine.Pin.OUT),
    cs=machine.Pin(9, machine.Pin.OUT),
    backlight=machine.Pin(13, machine.Pin.OUT),
    rotation=1
)

timer_pin = machine.Pin(15, machine.Pin.IN, machine.Pin.PULL_DOWN)   # Timer control (GP15)
next_pin = machine.Pin(19, machine.Pin.IN, machine.Pin.PULL_DOWN)    # Next scramble / show avgs (GP19)

faces = ['U', 'D', 'L', 'R', 'F', 'B']
modifiers = ['', "'", '2']
opposite = {'U':'D', 'D':'U', 'L':'R', 'R':'L', 'F':'B', 'B':'F'}

RESULTS_FILE = "cube_times.json"

'''
def draw_version():
    version_str = VERSION
    tft.fill_rect(255, 210, 60, 25, st7789.BLACK)
    tft.text(font_small, version_str, 255, 210, st7789.RED)
'''

def draw_version():
    """Draw version in bottom-right corner with proper calculations
    Based on the coordinates (255, 210) that worked previously (the function above)
    
    This is created with help from GitHub Copilot, using the previous function above"""
    version_str = VERSION
    
    # Calculate version string width
    version_width = font_small.WIDTH * len(version_str)
    
    # Calculate position - preserve the right and bottom offsets that worked
    x = 255 - (version_width - len("v1.1.0") * font_small.WIDTH)  # Adjust if version is longer than v1.1.0
    y = 210  # Keep the y position that worked
    
    # Clear background area with a bit of padding
    tft.fill_rect(x-2, y-2, version_width+4, font_small.HEIGHT+4, st7789.BLACK)
    
    # Draw version text
    tft.text(font_small, version_str, x, y, st7789.RED)

def load_times():
    try:
        with open(RESULTS_FILE, "r") as f:
            return ujson.load(f)
    except:
        return []

def save_times(times):
    try:
        with open(RESULTS_FILE, "w") as f:
            ujson.dump(times, f)
    except Exception as e:
        print(e)

def clear_times():
    try:
        with open(RESULTS_FILE, "w") as f:
            ujson.dump([], f)
    except Exception as e:
        print(e)

def generate_scramble(n_moves=20):
    scramble = []
    prev = None
    for _ in range(n_moves):
        while True:
            f = random.choice(faces)
            if f != prev and (prev is None or f != opposite[prev]):
                break
        m = random.choice(modifiers)
        scramble.append(f+m)
        prev = f
    return " ".join(scramble)

def wrap_scramble(scramble, max_line_len=15):
    words = scramble.split()
    lines = []
    current = ""
    for w in words:
        if len(current) + len(w) + 1 <= max_line_len:
            current += ("" if current == "" else " ") + w
        else:
            lines.append(current)
            current = w
    if current:
        lines.append(current)
    return lines

def display_scramble(scramble):
    tft.fill(st7789.BLACK)
    title = "RasPiCube - PicoCube"
    x_title = max(0, (TFT_WIDTH - font_big.WIDTH * len(title)) // 2)
    tft.text(font_big, title, x_title, 10, st7789.CYAN)
    subtitle = "Hold GP15 to prep"
    x_sub = max(0, (TFT_WIDTH - font_big.WIDTH * len(subtitle)) // 2)
    tft.text(font_big, subtitle, x_sub, 45, st7789.YELLOW)
    lines = wrap_scramble(scramble)
    block_height = len(lines) * 35
    y = max(70, (TFT_HEIGHT - block_height) // 2)
    for line in lines:
        x_line = max(0, (TFT_WIDTH - font_big.WIDTH * len(line)) // 2)
        tft.text(font_big, line, x_line, y, st7789.WHITE)
        y += 35
    draw_version()

def display_timer(time_val, running=True, clear_all=False):
    if clear_all:
        tft.fill(st7789.BLACK)
    
    timer_str = "{:6.1f}".format(time_val) if running else "{:6.2f}".format(time_val)
    x_timer = max(0, (TFT_WIDTH - font_big.WIDTH * len(timer_str)) // 2)
    y_timer = (TFT_HEIGHT - font_big.HEIGHT) // 2
    
    timer_width = font_big.WIDTH * len(timer_str)
    
    # Only clear the rectangle where the time will be displayed. This should increases the frame rate and reduce flickering
    tft.fill_rect(x_timer, y_timer, timer_width, font_big.HEIGHT, st7789.BLACK)
    
    tft.text(font_big, timer_str, x_timer, y_timer, st7789.GREEN if running else st7789.CYAN)

def avg_of(times, count):
    """
    Calculate average of count solves, trimming best and worst results for count >= 5
    For a standard Rubik's cube timer, both ao5 and ao12 require trimming.
    
    This function is created with assistance from GitHub Copilot, since my old method was not working
    """
    if len(times) < count:
        return None

    # Get the most recent 'count' times
    recent_times = [entry["time"] for entry in times[-count:]]

    # For ao5 and ao12, trim the best and worst times according to WCA standards
    sorted_times = sorted(recent_times)
    trimmed = sorted_times[1:-1]  # Remove best and worst
    return sum(trimmed) / len(trimmed)
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

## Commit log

2025-05-16 attempted to make it behave more like a real rubiks cube timer. added real time timer
2025-06-02 add file for case
    [RasPiCube_Case.step]
2025-06-02 move files
    [BOM-needed.csv, BOM.csv]
2025-06-07 update wifi adapter to use one with in-kernel driver support
2025-06-07 Update BOM-needed.md to change to a wifi adapter with in-kernel driver
2025-06-07 add symlink pointing to BOM
    [BOM.csv]
2025-06-07 rename BOM
2025-06-08 add bom link
2025-06-21 add files for pi pico.
2025-06-23 bug fix: continue not in loop
    [pico-rubiks.py]
2025-06-23 fix version display. tsym claude
    [pico-rubiks.py]
2025-06-23 copilot help me fixing the LCD sleep function :p
    [pico-rubiks.py]
2025-06-23 fix timer control
2025-06-24 fixed a critical bug
    [pico-rubiks.py]
2025-06-24 fix syntax error. idk what i did
    [pico-rubiks.py]
2025-06-24 critical bug fix. if i figure this out, there might be a minor release coming
    [pico-rubiks.py]
2025-06-26 update schematics
    [pcb.kicad_pcb, pcb.kicad_sch]
2025-06-26 update file needed to set up pi
    [config.txt]
2025-06-26 update config to disable wifi (i need usb wifi for 5ghz)
    [config.txt]
2025-06-26 remove pcb;
    [pcb.kicad_pcb, pcb.kicad_sch]
2025-06-27 bug fix and stuff
    [raspicube.py]
2025-06-27 hopefully a bug fix
    [raspicube.py]
2025-06-27 fix logging (`journalctl` was not working properly with `print()`)
    [raspicube.py]
2025-06-28 update gpu mem
    [config.txt]
